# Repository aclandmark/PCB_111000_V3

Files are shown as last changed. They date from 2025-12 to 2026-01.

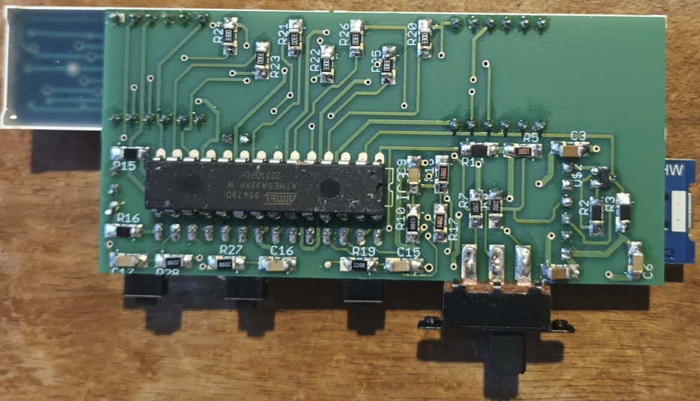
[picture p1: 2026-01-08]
Version 3 design/PCB111000_V3_track side.bmp

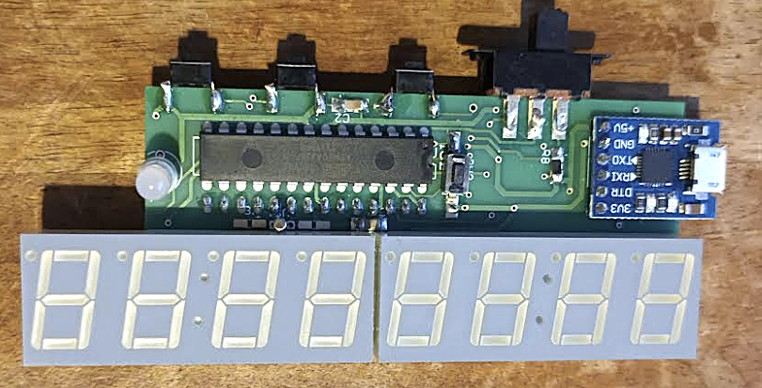
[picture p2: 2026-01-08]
Version 3 design/PCB111000_V3_top side.bmp

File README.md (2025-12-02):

# PCB_111000_V3
This version of PCB_111000 uses a CP2102 USB module
to enable the Atmega devices to communicate with a PC.
This replaces the discreet components used in versions 1 and 2.  
It also makes the PCB cheeper and easier to assemble.

There is one other change: The device that hosts user projects,
an Atmega 168 has been replaced with an Atmega 328.
User projects should not be affected but should be compiled for the
Arduino UNO pcb rather than for the Arduino Nano with an Atmega 168.

Set up procedure for PCB_111000_V3 is the same as that for V2 however
there are slight differences in the programs.
8_UNO_AVR_Programmer_V3 is replaced by UNO_PCB_111000_V3_programmer
5_Project_pcb_168_V2.30_Arduino_V2 is replaced by mini_OS programmer

The original mini-OS generated the user prompt p/r  p/r  p/r.......
An special version was developed that enabled user projects to reset the
mini-OS in the event of a crash.  This version generates the user prompt
p/g  p/g  p/r......... It will ber used in PCB_111000_V3.

No additional changes are expected for the mini-OS, so only the hex files 
are copied into this repository.

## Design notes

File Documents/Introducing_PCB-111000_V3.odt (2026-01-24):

PCB_111000_V3: Getting a new pcb up and running

1. Introduction

PCB_111000_V3 is a development of PCB_111000_V2.

Both pcbs are loaded with two Atmega 328 devices rather than one Atmega328 and one Atmega168.

The first Atmega 328 hosts user projects (The user device).

The second 328 (the mini-OS device) hosts a mini-OS which:

Drives an 8 digit display

Includes an Atmega programmer to programs the user device.

Provides a variety of services for use by user projects

PCB initialisation is carried out using the following Arduino sketches

UNO_PCB_111000_V3_programmer (was 8_UNO_AVR_programmer_V3)

mini_OS programmer (was 5_Project_pcb_168_V2.30_Arduino_V2)

2. Setting up PCB-111000_V2: Basic steps

Step 1 The PCB is loaded with all components except the displays and the Atmega devices

Step 2

Open the sketch “UNO_PCB_111000_V3_programmer”. Under Tools/Board select Arduino UNO. Connect the UNO to the PC check the port number and upload the sketch.

Step 3

Close the sketch assemble the HW (see section 3) and with the aid of the Br@y++ terminal emulator use the UNO to:

Upload “mini_OS programmer” to the user device

Calibrate it’s internal RC oscillator

Allow the user device to run so that it can upload string data to its EEPROM.

Note:

Terminal emulator runs at 38.4KB and uses default settings.

See section 4 for more details.

Step 4 Load the user device onto the PCB111000_V3 and test, then add the mini-OS device.

Step 5

Run “mini_OS programmer” under the control of Br@y++ to setup the mini-OS device (See section 5 for more details) by:

Uploading the mini-OS to its flash

Checking the calibration of its internal RC oscillator.

Uploading the “Hello world” strings to its EEPROM

Step 6 Overwrite “mini_OS programmer” with user projects.

(See sections 6 and 7.)

Step 7 Upgrade the mini_OS if necessary (See section 8).

3. Hardware (HW) details

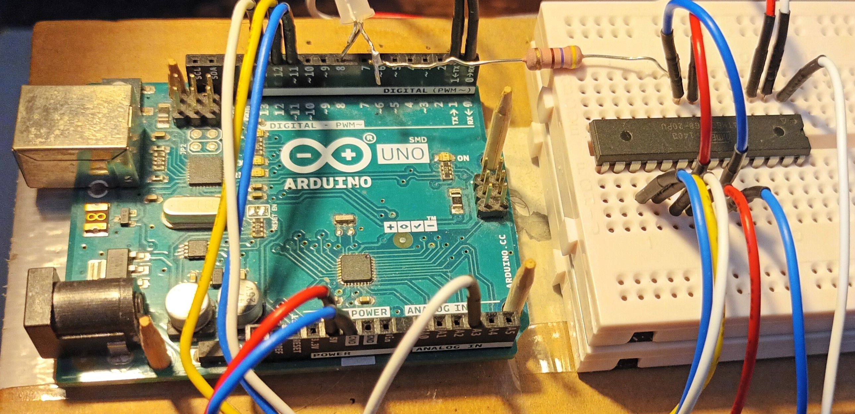
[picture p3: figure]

UNO used to program the user device before it is soldered onto the PCB111000_V3 Note: Atmega328 pin numbers given for a DIP28 device Upload “UNO_PCB_111000_V3_programmer” sketch before placing the user device | UNO | | | Plug-in pcb
| UNO Pin | Atmega 328 | | User device
| | Pin | Function | Pin
| 0 (Rx) | 2 | RXD | 2
| 1 (Tx) | 3 | TXD | 3
| 11 | 17 | MOSI | 17
| 12 | 18 | MISO | 18
| 13 | 19 | SCK | 19
| A3 | 26 | PC3 | 1 (Reset)
| GND | | | 8, 22
| 5V | | | 7,20
| 8 | 14 | PB0 | LED driver

4. Driving “UNO_PCB_111000_V3_programmer”

Having uploaded the sketch to a UNO open Br@y++ and set it up as follows:

8 data bits, 1 stop bit, no parity or handshaking and a baud rate of 38.4KB

Click on “scan” to identify the comm port and then click on connect:

The following user prompt should be generated:

“s/x s/x s/x s/x s/x s/x s/x…………….”

Step 1 Click mouse pointer in the text box (at the bottom of the Br@y++ window) and

press -s- to get

“Atmega 328 detected.

Press -p- to program flash, -r- to run target, -d- to clear the target EEPROM or -x- to escape.”

Step 2 Press -p- and send “mini_OS programmer”

Step 3 Follow instructions to Cal device then get user prompt “P/S P/S P/S………….”

Step 4 Press -s-, change bit rate when asked and send Text_files\on-chip_strings.txt

A bug Sometimes random text following programming. Power cycle and reprogram.

Optional steps

At P/S prompt press -v- to get program name plus version “mini_OS programmer_V1”

Reset UNO and change the BR to 38.4kB to restore user prompt “s s s s s s s…………….”

Press -s- then -d- to clear “on-chip_strings” and cal bytes from the user device EEPROM

Reset UNO to restore user prompt “s s s s s s s…………….”

Press -s- then -t- to recalibrate the Atmega 328 and restore user prompt “P/S P/S…...…”

Reset UNO to restore user prompt “s s s s s s s…………….”

Press -s- then -r- to restore user prompt “P/S P/S P/S………….”

Press -s- and reprogram the on-chip strings

Reset UNO to restore user prompt “s s s s s s s…………….”

Press -s- then -x- to escape

Reprogram the user device and note that it now offers a recalibration

5 Driving “mini_OS programmer”

5.1 Add the user device

Solder the User device to the PCB-111000_V3.

Press the DPDT switch left

Connect the pcb to a PC running Br@y++ running at 57.6KB.

Check the port and the user prompt “P/S P/S P/S…………..” should be generated.

Press -p- and the response TTND (Target not detected) should also be generated.

This confirms that the USB port is working correctly.

5.2 Add the mini-OS device

Solder on the mini-OS device and press -p- again to generate the prompt:

“ATMEGA 328 detected

Press -P- to send a program file -E- to send a text file (or X to escape).

p/e p/e p/e p/e p/e p/e…..”

5.3 Upload the mini-OS hex file

Press -p- and send

PCB_111000_V3\mini-OS_HEX_files\mini_OS_CC_display.hex

When the LED stops flashing send pcb_bootloader_CC.hex

Note: This assumes that Common Cathode displays are to be used. Similar files are present for Common Anode displays.

5.4 Auto cal the mini-OS device

Follow instructions to auto cal the mini-OS device and restore the “P/S……” prompt.

5.5 Upload the “Hello_world” file to the mini-OS device EEPROM

Press -p- then -e- then -w- and send “Text_files\Hello_world.txt several times as requested.

Finally press any key to read back the file from EEPROM.

6. Run two simple User Projects

6A To test programmer

Press the DPDT switch right to get the “p/g p/g p/g …...” (May need to press the pcb reset switch.)

Press -p- and send

PCB_111000_V3\setup_projects\First_test_proj\First_test_proj.ino.standard.hex

At the “p/g p/g p/g …...” prompt press -g- and operate the DPDT switch.

A column of numbers will be printed out.

Press sw1 to repeat.

6B To test the I2C bus

Send PCB_111000_V3\setup_projects\Get_mini_OS_version\Get_mini_OS_version.hex

Press x at the p/g prompt and then 3 to download hello world messages.

If these projects ruin as expected the displays can now safely be added.

7. Load and check the displays

Displays are driven using a multiplexer which can make fault finding difficult.

Repeat as for section 6 but send “PCB_test\PCB_test.ino.standard.hex”. This turns off the multiplexer and illuminates digits one at a time.

Check for dry joints or solder bridges if any segments fail to work.

7A Display brightness

Reload “Get_mini_OS_version.hex” and press -x- at p/g prompt. Then press 4 while holding 2 user switches down.

7B Default user project

Reload “mini_OS_reset.ino.standard. hex”. and press -x- at p/g prompt. This will give the default project.

8. To upgrade the mini_OS

Push the DPDT switch right and press the reset switch.

Press -p- at the “p/g p/g p/g p/g p/g….” user prompt

and send mini_OS programmer

Run the project to get the “P/S P/S P/S………….”

Press S and reload file “on-chip_strings.txt” containing programmer strings

Press P then upload the new mini-OS as described in section 5.3

Note: Remember to delete line :00000001FF from end of new mini-OS file

9. Optional system files

Mini-OS_Resources\Eeprom_subroutines_PRN_alt.c:

In early designs PRN generator write to the EEPROM was too frequent and EEPROM burnout occurred. In this file the PRN uses a different location. It should be used if the

Message from the OS is always the same.

Bootloader_resources\Bootloader_main_with_OS_reset.c

This enables user projects to reset the mini-OS which is necessary if the I2C bus crashes. It was optional for PCB_111000_V2 but is standard for PCB_111000_V3.

See section 14 for more details.

10 SW downloads

There are two essential software applications that must be downloaded onto this PC. They are:

The Arduino development environment. Go to https://www.arduino.cc/en/software and download it from the Microsoft store.

Bray++ version 20130820 which can be downloaded from https://www.sites.google.com/site/terminalbpp/

Almost as important are

The portable version of Programmers notepad which can be downloaded from

http://www.pnotepad.org/download/.

An excellent text written by Joe Pardue that can be downloaded from

https://epdf.pub/c-programming-for-microcontrollers.html

The Atmega data sheet that can be downloaded from

https://www.docdroid.net/Q6jfzd3/atmega48a-pa-88a-pa-168a-pa-328-p-ds-ds40002061a-pdf

11 Getting the PCB manufacturing files

Open the board in Eagle fusion.

Click on the manufacturing tab.

Click on the Export Gerber NC drill……. manufacturing icon then OK

Save as a CamOutputs.zip file when requested

Can now extract files to a CamOutputs directory and remove the “assembly folder” leaving

“DrillFiles” and “GerberFiles” before recompressing the directory.

Send this to a pcb manufacturer.

12. PCB assembly

Fusion/Eagle circuit design and layout drawings can be found under

PCB-111000_V3\Version 3 design together with a parts list.

The Eagle pcb design software is required to view these

Photographs of the pcb are shown below.

Note the locations of the following components

The user switches sw1, sw2 and sw3

The double pole double throw switch (DPDT)

The reset switch

The user device which is in the top side of the pcb (note also the location of pin 1)

The Mini-OS device which is in the under side of the pcb (note also the location of pin 1)

Because of the way the two Atmega devices are assembled the pins of one of them must be soldered from the device side of the board.

Note also the orientation of the two display modules.


| Photo of PCB-111000V3 track side. Solder the mini-OS device to this side Note its placement with pin 1 (towards the middle of the pcb).

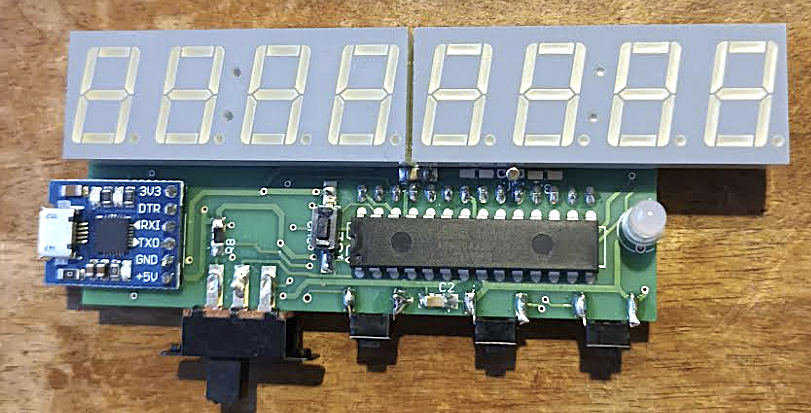
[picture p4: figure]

| Photo of PCB-111000V3 component side. Solder the user device to this side Note its placement with pin 1 (towards the middle of the pcb). User switches left to right are sw1, 2 &3 Note also the orientation of the display modules
Other switches are the DPDT and the reset switch

13 System Block diagram

User device hosts user programs.

Mini-OS device hosts programmer and I2C/display……..application

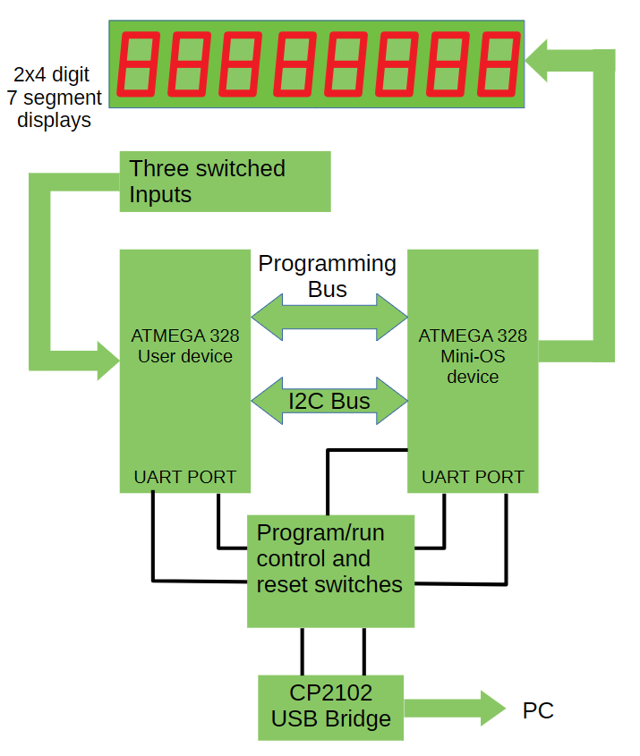
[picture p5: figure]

14 Reset functions

There are three applications that may need to be reset:

The user project.

The programmer

The I2C/display driver

The reset switch

Resets the user project

Passes control in the mini-OS device to the programmer (i.e. a jump to the boot section).

Occasionally it is necessary to

Reset the user project

Pass control in the mini-OS device to the I2C/display code, (a jump to the application section).

This is referred to as a full reset and can be used when a project crashes and the reset switch fails to restart things as required.

To implement a full reset:

User code includes a watch dog time out with ISR.

Control jumps to the ISR when the I2C bus crashes.

This uses a programming wire to signal the mini-OS device and then

applies pulse to its reset pin.

Finally the ISR times out and the user device resets.

Note:

The ISR can also save the variables needed to ensure that the project resumes as required.

Full reset will only be applied to user projects when needed. As an example it has been implemented in

setup_projects\mini_OS_reset\mini_OS_reset.ino.

To indicate that the mini-OS has been implemented to accept full reset the user prompt is changed from

p/r p/r p/r……… to p/g p/g p/g……..

15 Issues

If -p- is pressed at the p/g prompt the first task of the programmer is to switch the target device into programming mode after which its programming memory is reset and the user is requested to send the code. Occasionally the device fails to enter programming mode. It is believed that this unpredictable response may be due to a dry joint in the reset circuitry.

Having pressed -p- at the p/g prompt the user device program space is cleared, in other words the original program can no longer function. In some versions of PCB 111000 this process was delayed until the first character of the new code had been received so that users could safely change their minds after pressing p. This has not been implemented here however as it was not found to be adequately reliable.

The original mini-OS was developed using winAVR will full optimisation, in other words to make the executable file as small as possible. winAVR has been replaced by Studio 7 which generates even smaller code. Optimisation has had to be turned off. The reasons for this have not been investigated but may be due to timing issues.

EEPROM address changes V2 top V3

Cal factors

0x1FF becomes 0x3FF User OSC CAL

0x1FE 0x3FE User OSC CAL

0x1FD 0x3FD Default OSC CAL

0x1FC 0x3FC PRN location

0x1FB 0x3FB PRN location

0x1FA 0x3FA Reset source

0x3F9 Used by mini-OS programmer

All projects: Recompile with new EEPROM locations

Setup projects: All tested

Glitch in reading hello world file:

Text “Do it your own way! Let the others only think they know best”

reads as “Do it your own way! Let the othothers only think they know best”

When downloading and printing files a Tx delay may need setting up in Bray++

All projects recompiled and tested OK

Check text at head of Arduino projects All done

For all projects including Proj_0 use pcb_111000_projects C files

A V3 pcbs loaded and checked except for Displays

Check for !UC !UC !UC response on V1

All OK bar one which was cured by pressing on plug in user device

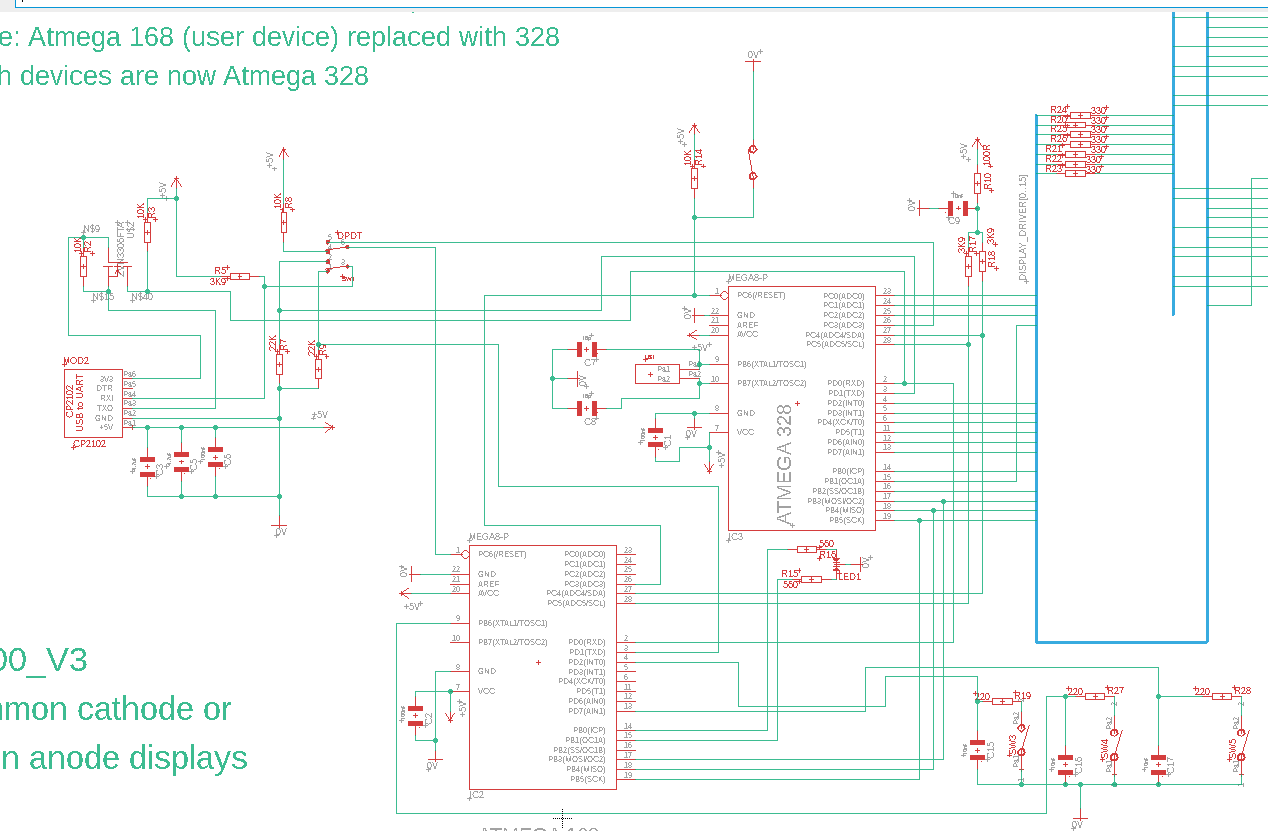
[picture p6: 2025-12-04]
Version 3 design/Schematic.bmp

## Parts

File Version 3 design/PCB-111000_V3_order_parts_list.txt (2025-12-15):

Partslist

Capacitors

18pF (C7, C8)				2 OFF			RS 648-0935		OK	Ordered			RECEIVED
10nF (C9, C15, C16, C17)  		4 OFF			RS 199-2068		OK	Ordered			RECEIVED
100nF (C1, C2, C6) 			3 OFF			RS 669-8417		OK	Ordered			RECEIVED
4.7uF (C3, C5)				2 OFF			RS 723-5076		OK	Ordered			RECEIVED

C4, C10 to 14 missing

Resistors

220R (R27, R28)				2 OFF			RS 812-1849		OK	Ordered			RECEDIVED
330R (R20 to 26)			7 OFF			RS 197-8302		OK	Ordered			RECEIVED
560R (R15, R16)				2 OFF			RS 679-2225		OK	Ordered			RECEIVED
3K9	(R5, R17, R18)			3 OFF			RS 242-6578		OK	Ordered			RECEIVED
10K	 (R2, R3, R8, R14)		4 OFF			RS 679-1765		OK	Ordered			AWAITING
22K	(R7, R9)			2 OFF			RS 223-2439		OK	Ordered			RECEIVED

R1, R4, R6, R11, R12, R13 missing

R10 100R not ordered	Used 220R instead

CC_DUAL_LED			1 OFF		RS 171-2136	OK	Ordered			RECEIVED
Watch Crystal 			1 OFF		RS 171-0553	OK	Ordered			RECEIVED
MOSFET ZVN3306FTA		1 OFF		RS 275-945	OK	Ordered			RECEIVED

Extras
6 way header x 3 Radio Spares 				681-2994				RECEIVED 
Bread board jumper wires		RS Stock No.:	505-3374	505-3403 		RECEIVED
2 Watt wired resistor 					707-8849				RECEIVED 				

Others
4_DIGIT_7SEGMENT_DISPLAY		CA56-12SYKWA	2 OFF	872-1954	Ordered		RECEIVED

4_DIGIT_7SEGMENT_DISPLAY	CC56-21SURKWA	RS 165-4368  Pack of ten NOT AVAZILABLE

Atmega 328	ATMEGA328-PU	RS 131-0277			OK	
Atmega 168	ATMEGA168PA-PU	RS 127-8268			OUT OF STOCK	

For parcell tracking
Sold to				12277347
Order ref number	3015071146

CP2102 					1 OFF
DPDT switch				1 OFF		RE  78-0560	OK
SM NO push button 		1 OFF		RE 51-0709 	OK
Push button switch		3 OFF		RE 51-0711	OK
Solder wick							Ordered from RE

      DHL eCommerce UK Swindon
      Unit 1 Ignition Park
      Dorcan
      Swindon
      SN3 5HS
Sender s reference: 1259602840 

Your shipment 31542913837470 (1 parcel expected) is delivered
Sender s reference: 1259602840

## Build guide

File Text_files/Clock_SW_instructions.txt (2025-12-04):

"Having entered the time it is also possible to reconnct the pcb to a 5V supply.Then press sw3/sw1 to start the clock. 
Toggle sw1 to switch between the clock and a new SW or press sw2 to select old SW.
Press sw3 to pause, blank or resume the display.
To adjust the time: Press sw1 to restore clock time then immediately press sw3.
Release sw3 to increment time or sw1 to decrement it then both switches to restore normal operation.
Press sw3 or 2 then sw1 to continue."

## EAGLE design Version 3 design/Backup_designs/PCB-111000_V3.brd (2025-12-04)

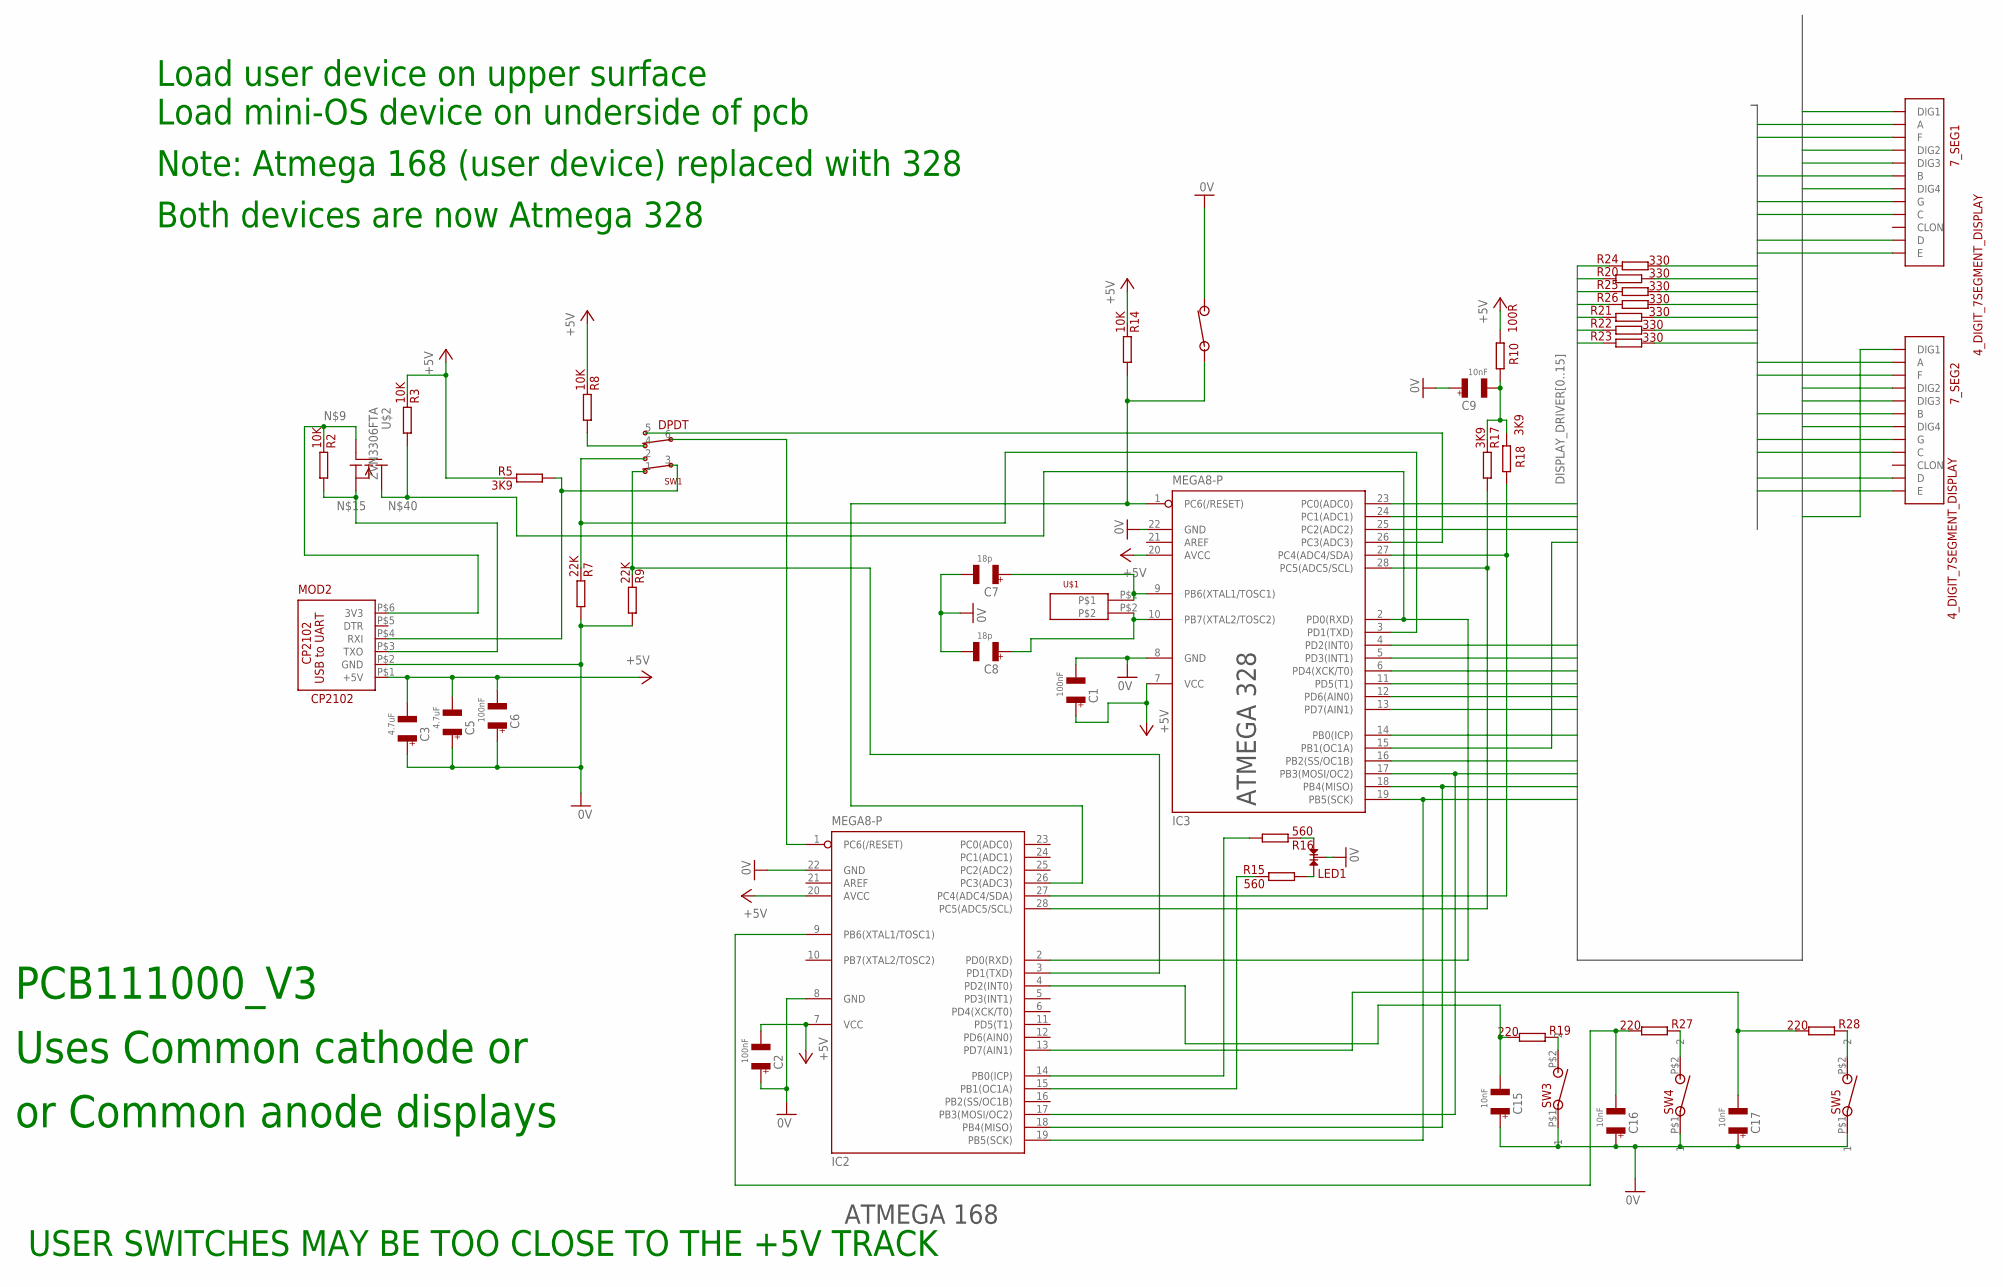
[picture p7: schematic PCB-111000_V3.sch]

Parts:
7_SEG1, 7_SEG2: 4_DIGIT_7SEGMENT_DISPLAY
C1, C2, C6: 100nF; 1206@1
C3, C5: 4.7uF; 1206@1
C7, C8: 18p; 0805
C9, C15, C16, C17: 10nF; 1206@1
IC2, IC3: MEGA8-P; DIL28-3
LED1: LED; CA_DUAL_LED
MOD2: CP2102
R2, R3, R8, R14: 10K; 1206
R5, R17, R18: 3K9; 1206
R7, R9: 22K; 1206
R10: 100R; 1206
R15, R16: 560; 1206
R19, R27, R28: 220; 1206
R20, R21, R22, R23, R24, R25, R26: 330; 1206
SW1: DPDT; DPDT_SWITCH
SW2: NO_SW; SM_NO_PUSH_BUTTON
SW3, SW4, SW5: NO_PB_1; RE51-0711
U$1: XTAL; XTAL_VIAS
U$2: ZVN3306FTA; SOT-23

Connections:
0V: C1.P$2 (2), C2.P$1 (1), C3.P$1 (1), C5.P$1 (1), C6.P$1 (1), C7.2, C8.2, C9.P$1 (1), C15.P$1 (1), C16.P$1 (1), C17.P$1 (1), IC2.8 (GND), IC2.22 (GND), IC3.8 (GND), IC3.22 (GND), LED1.2, MOD2.P$2 (GND), R7.P$1, R9.P$1, SW2.P$2 (2), SW3.P$1 (1), SW4.P$1 (1), SW5.P$1 (1)
+5V: C1.P$1 (1), C2.P$2 (2), C3.P$2 (2), C5.P$2 (2), C6.P$2 (2), IC2.7 (VCC), IC2.20 (AVCC), IC3.7 (VCC), IC3.20 (AVCC), MOD2.P$1 (+5V), R3.P$2, R5.P$2, R8.P$2, R10.P$2, R14.P$2
DISPLAY_DRIVER0: IC3.15 (PB1(OC1A)), R24.P$2
DISPLAY_DRIVER1: IC3.4 (PD2(INT0)), R20.P$2
DISPLAY_DRIVER2: IC3.5 (PD3(INT1)), R25.P$2
DISPLAY_DRIVER3: IC3.6 (PD4(XCK/T0)), R26.P$2
DISPLAY_DRIVER4: IC3.11 (PD5(T1)), R21.P$2
DISPLAY_DRIVER5: IC3.12 (PD6(AIN0)), R22.P$2
DISPLAY_DRIVER6: IC3.13 (PD7(AIN1)), R23.P$2
DISPLAY_DRIVER8: 7_SEG2.P$12 (DIG1), IC3.14 (PB0(ICP))
DISPLAY_DRIVER9: 7_SEG2.P$9 (DIG2), IC3.16 (PB2(SS/OC1B))
DISPLAY_DRIVER10: 7_SEG2.P$8 (DIG3), IC2.17 (PB3(MOSI/OC2)), IC3.17 (PB3(MOSI/OC2))
DISPLAY_DRIVER11: 7_SEG2.P$6 (DIG4), IC2.18 (PB4(MISO)), IC3.18 (PB4(MISO))
DISPLAY_DRIVER12: 7_SEG1.P$12 (DIG1), IC2.19 (PB5(SCK)), IC3.19 (PB5(SCK))
DISPLAY_DRIVER13: 7_SEG1.P$9 (DIG2), IC3.23 (PC0(ADC0))
DISPLAY_DRIVER14: 7_SEG1.P$8 (DIG3), IC3.24 (PC1(ADC1))
DISPLAY_DRIVER15: 7_SEG1.P$6 (DIG4), IC3.25 (PC2(ADC2))
unnamed: IC2.14 (PB0(ICP)), R16.P$1
unnamed: IC2.15 (PB1(OC1A)), R15.P$2
unnamed: LED1.1, R15.P$1
unnamed: LED1.3, R16.P$2
unnamed: IC3.26 (PC3(ADC3)), SW1.5
unnamed: IC3.3 (PD1(TXD)), R7.P$2, SW1.2
unnamed: R27.P$2, SW4.P$2 (2)
unnamed: R19.P$2, SW3.P$2 (2)
unnamed: MOD2.P$6 (3V3), R2.P$2, U$2.3 (G)
unnamed: C7.1, IC3.9 (PB6(XTAL1/TOSC1)), U$1.P$1
unnamed: C17.P$2 (2), IC2.13 (PD7(AIN1)), R28.P$1
unnamed: C8.1, IC3.10 (PB7(XTAL2/TOSC2)), U$1.P$2
unnamed: R8.P$1, SW1.4
unnamed: IC2.3 (PD1(TXD)), R9.P$2, SW1.1
unnamed: MOD2.P$3 (TXO), R2.P$1, U$2.2 (S)
unnamed: R28.P$2, SW5.P$2 (2)
unnamed: C15.P$2 (2), IC2.4 (PD2(INT0)), R19.P$1
unnamed: C16.P$2 (2), IC2.9 (PB6(XTAL1/TOSC1)), R27.P$1
unnamed: C9.P$2 (2), R10.P$1, R17.P$2, R18.P$2
unnamed: IC2.1 (PC6(/RESET)), SW1.6
unnamed: IC2.26 (PC3(ADC3)), IC3.1 (PC6(/RESET)), R14.P$1, SW2.P$1 (1)
unnamed: MOD2.P$4 (RXI), R5.P$1, SW1.3
unnamed: IC2.28 (PC5(ADC5/SCL)), IC3.28 (PC5(ADC5/SCL)), R17.P$1
unnamed: IC2.27 (PC4(ADC4/SDA)), IC3.27 (PC4(ADC4/SDA)), R18.P$1
unnamed: IC2.2 (PD0(RXD)), IC3.2 (PD0(RXD)), R3.P$1, U$2.1 (D)
SEVEN_SEG0: 7_SEG1.P$11 (A), 7_SEG2.P$11 (A), R24.P$1
SEVEN_SEG1: 7_SEG1.P$7 (B), 7_SEG2.P$7 (B), R20.P$1
SEVEN_SEG2: 7_SEG1.P$4 (C), 7_SEG2.P$4 (C), R25.P$1
SEVEN_SEG3: 7_SEG1.P$2 (D), 7_SEG2.P$2 (D), R26.P$1
SEVEN_SEG4: 7_SEG1.P$1 (E), 7_SEG2.P$1 (E), R21.P$1
SEVEN_SEG5: 7_SEG1.P$10 (F), 7_SEG2.P$10 (F), R22.P$1
SEVEN_SEG6: 7_SEG1.P$5 (G), 7_SEG2.P$5 (G), R23.P$1

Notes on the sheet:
ATMEGA 168
ATMEGA 328
or Common anode displays
PCB111000_V3
Uses Common cathode or
USER SWITCHES MAY BE TOO CLOSE TO THE +5V TRACK
Load mini-OS device on underside of pcb
Load user device on upper surface
Note: Atmega 168 (user device) replaced with 328
Both devices are now Atmega 328

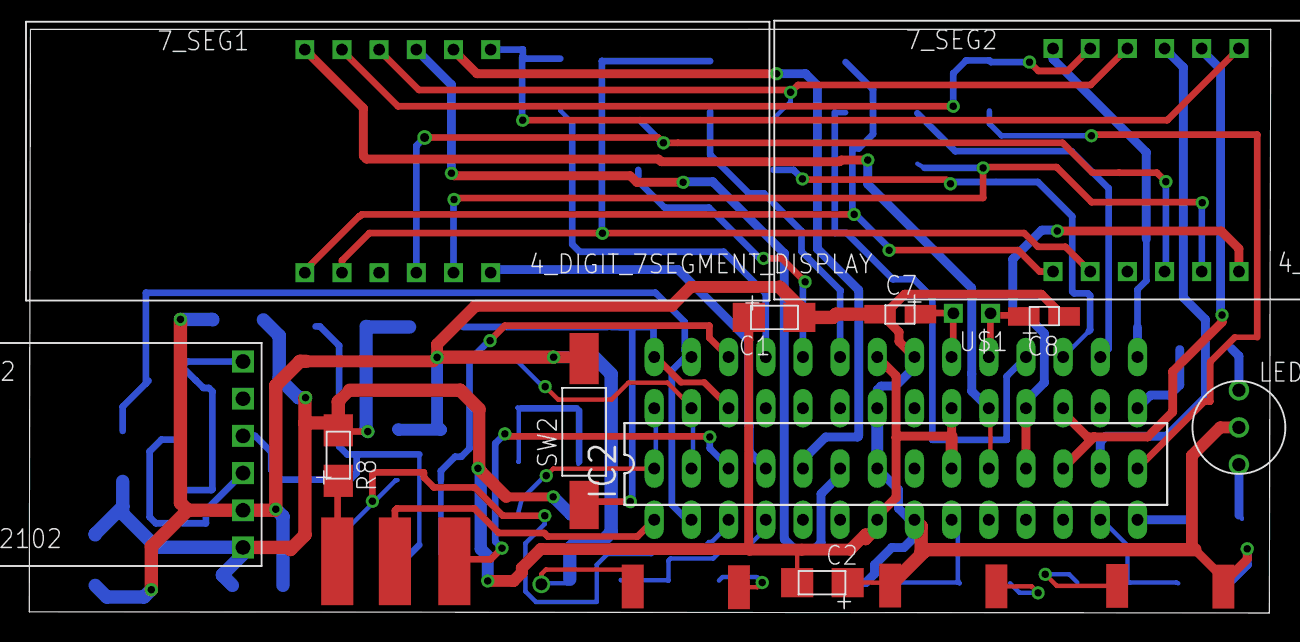
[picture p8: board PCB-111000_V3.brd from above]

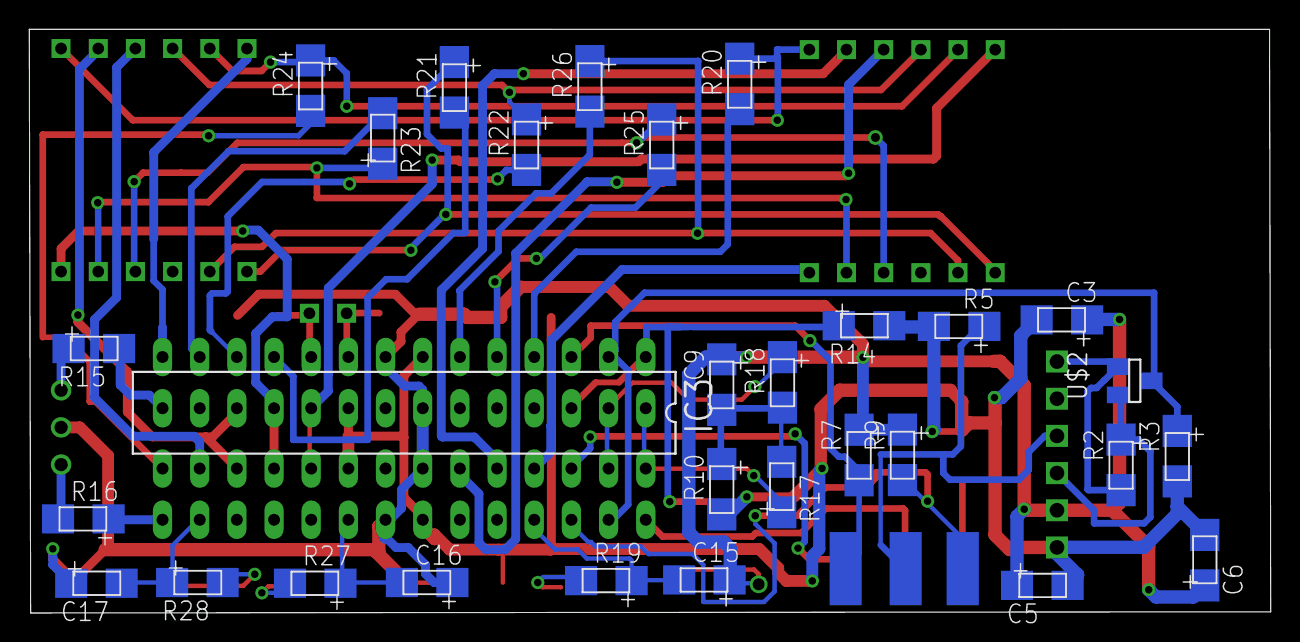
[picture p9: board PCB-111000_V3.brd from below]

Board: 2 copper layers, 84.8 x 39.9 mm, 46 parts (31 on the bottom side), 49 nets.

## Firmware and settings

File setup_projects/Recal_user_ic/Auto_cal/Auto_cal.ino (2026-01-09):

/*Proj_9B_168_auto_cal
************************************************************************/


/*IT INTRODUCES

1.  Project subroutine "emergency_cal()". 
  This is like subroutine "compute_error()" but quicker and less accurate.

2.  Project subroutine "Calibration_tuning()".
  This automatically attempts to find the best value for OSCCAL.

Note: Proj_9B can be used if the default value of OSCCAL is not good enough for PC comms. */


#include "Proj_9B_header_file.h"


volatile char T1_OVF;
volatile long error_SUM;
unsigned char OSCCAL_WV, OSCCAL_DV, New_UC_value;
volatile int EA_counter, EA_buff_ptr;
char cal_mode;
char Num_string[12];


int main (void){
long error;

setup_HW_Arduino_IO;                                                  //"setup_HW" initially saves default OSCCAL in 0x3FD and

TIMSK1 |= (1 << TOIE1);                                               //Enable T1 interrupt
I2C_initiate_7_8125mS_ref();                                           //Request Mode P: 7.8125mS ref signal from master


/*****Waiting for first I2C tick***********/
waiting_for_I2C_master;                                                //Energise slave I2C and wait for master
send_byte_with_Nack(1);                                               //Master will respond by staying in mode P
clear_I2C_interrupt;                                                  //House keeping
TCNT1=0;TCCR1B = 1;                                                   //Start T1 with no pre-scaling (at 8MHz)
sei();  


cal_mode = 1;   
for(int m = 0; m < 15; m++)error = emergency_cal();                   //warm-up time

for(int m = 0x10; m <= 0xF0; m++){                                    //results are stored in array "buffer"
OSCCAL = m; if (!(m%5))Serial.write('.');
if ((error = emergency_cal()) < 1000)break;}
waiting_for_I2C_master;
send_byte_with_Nack(0);                                             //Master responds by exiting mode P
clear_I2C_interrupt;
TIMSK1 &= (~(1 << TOIE1));                                          //Disable T1 interrupt
newline_A(); 
Serial.write("Approx. cal factor ");Hex_to_PC_A(OSCCAL, Num_string, ' ');  
Serial.write("   Error "); Int_Num_to_PC_A(error, Num_string, '\r');

cal_mode = 5;
TIMSK1 |= (1 << TOIE1);                                               //Enable T1 interrupt
I2C_initiate_7_8125mS_ref();    
waiting_for_I2C_master;
send_byte_with_Nack(1);                                               //Master responds by staying in mode P
clear_I2C_interrupt;
TCNT1=0;TCCR1B = 1;                                                   //Start T1
sei();                                                                //Global interrupt enable
OSCCAL_WV = OSCCAL;
error =  Calibration_tuning(OSCCAL_WV);                               //Fine tuning: First step may terminate in a subsidiary dip 
if (error > 500) error =  Calibration_tuning(OSCCAL + 4);             //Fine tuning: Second step to locate main dip 
if (error > 500) error =  Calibration_tuning(OSCCAL - 2);
if (error > 500) OSCCAL_WV = OSCCAL;

waiting_for_I2C_master;
send_byte_with_Nack(0);                                               //Master responds by exiting mode P
clear_I2C_interrupt;
Serial.write("Cal factor ");
Hex_to_PC_A(OSCCAL, Num_string, ' ');
Serial.write("   Error ");
Int_Num_to_PC_A(error, Num_string, ' ');


Serial.write("\r\nSave? y or AOK\r\n");
if(waitforkeypress_A() == 'y'){
New_UC_value = OSCCAL;


eeprom_write_byte((uint8_t*)0x3FE, New_UC_value);                     //Save new user cal value to EEPROM addresses 0x1F7 and 8
Timer_T0_sub(T0_delay_10ms);
eeprom_write_byte((uint8_t*)0x3FF, New_UC_value);
Timer_T0_sub(T0_delay_10ms);

    
Serial.write("Values saved to EEPROM   ");                              //Echo values back from the EEPROM
Hex_to_PC_A(eeprom_read_byte((uint8_t*)0x3FE), Num_string, ' ');
Serial.write ("    ");
Hex_to_PC_A(eeprom_read_byte((uint8_t*)0x3FF), Num_string, ' ');
newline_A();}
else Serial.write("Not saved\r\n");

Serial.write("\r\nAK to repeat\r\n");
  waitforkeypress_A();SW_reset;}




/**********************************************************************************************/
long emergency_cal(void)  
    {long error;
    waiting_for_I2C_master_with_ISR;                                //TWI generates interrupt every 7.8125mS 
    EA_counter = 0;                                                 //Compute error for each value of OSCCAL 10 times
    error_SUM = 0;
    while(EA_counter < 2);EA_counter = 0;TWCR = 0;                  //wait here for 2 TWI interrupts
    error = error_SUM;
    if (error < 0) error *= (-1);                                   //Only interested in the magnitude of the error
    return error;}                                                  //return average error values
  


/**********************************************************************************************/
long compute_error(void)  
    {long error;
    waiting_for_I2C_master_with_ISR;
    EA_counter = 0;                                                   //Compute error for each value of OSCCAL 10 times
    error_SUM = 0;
    while(EA_counter < 15);EA_counter = 0;TWCR = 0;                    //wait here for 15 TWI interrupts
    error = error_SUM;
    if (error < 0) error *= (-1);                                     //Only interested in the magnitude of the error
    return error/10;}                                                 //return average error values



/**********************************************************************************************/
ISR(TIMER1_OVF_vect){T1_OVF++; }                                        //T1 should count to 62500 in 7.8125ms.



/************************************************************************************************/
ISR(TWI_vect){                                                          //T2 (mini_OS) overflows: giving a calibrated tick rate
long TCNT1_BKP;
TWDR;                                                                   //Read TWDR the data register
send_byte_with_Nack(1);                                                 //Master responds by remaining in mode P
clear_I2C_interrupt;

TCCR1B = 0;                                                             //Halt T1
TCNT1_BKP = TCNT1;                                                      //Copy the value of TCNT1
TCNT1 = 0;                                                              //Clear TCNT1
TCCR1B = 1;                                                             //Get T1 running again ASAP (Note T2 (mini_OS) has not stopped running)
if(EA_counter < cal_mode)T1_OVF = 0;                                    //Ignore first result for "emergency_cal()" or first 5 for "compute_error"
else
{switch(T1_OVF){
case 0: error_SUM = error_SUM + (TCNT1_BKP - 62500); break;
case 1: error_SUM = error_SUM + (TCNT1_BKP - 62500 + 65536); break;
case 2: error_SUM = error_SUM + (TCNT1_BKP - 62500 + 131072); break;}
T1_OVF = 0;}                                                             //Sum error results fo the next 20 TWI interrupts
EA_counter++;                                                            //counter increments up to 25.
waiting_for_I2C_master_with_ISR;}                                       //Be ready for next TWI interrupt 



/**********************************************************************************************/
/*void I2C_initiate_7_8125mS_ref(void){
char num_bytes=0;
char mode = 'U';
waiting_for_I2C_master;
send_byte_with_Ack(num_bytes);
send_byte_with_Nack(mode);
clear_I2C_interrupt;} */


/**********************************************************************************************/  
long Calibration_tuning(char OSCCAL_test)
    {long cal_error, error_mem; 
    OSCCAL = OSCCAL_test;   
    cal_error = compute_error();                                      //compute error for OSCCAL_test
    error_mem = cal_error;
    OSCCAL++;                                                        //increment OSCALL
    while(1){
    cal_error = compute_error();                                      //Calculate new error
    if (cal_error > error_mem) {                                      //If it gets worse
    OSCCAL--; break;}                                                 //decrement OSCCAL and exit             
    error_mem = cal_error;              
    OSCCAL++;}
    if (OSCCAL != OSCCAL_test)  return error_mem;                     //REPLACE with OSCCAL_DV when OSCCAL_test is discarded
    else{                                                             //OSCCAL is still the default value
    OSCCAL--;
    while(1){
    cal_error = compute_error();
    if (cal_error > error_mem){                                       //If it gets worse
    OSCCAL++;
    break;}                                                           //increment OSCCAL and exit
    error_mem = cal_error;              
    OSCCAL--;}}
    return error_mem;}



    /*************************************************************************************************************************************/

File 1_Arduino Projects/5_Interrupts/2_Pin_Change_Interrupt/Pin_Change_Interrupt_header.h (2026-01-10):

#include <avr/wdt.h>

char watch_dog_reset = 0;

#define T0_delay_10ms 5,178
#define T1_delay_100ms 3, 0x9E62
#define T2_delay_10ms 7,178


#define set_up_PCI_on_sw2           PCICR |= (1 << PCIE0);
#define enable_pci_on_sw2           PCMSK0 |= (1 << PCINT6);


#define switch_3_down  ((PIND & 0x80)^0x80)
#define switch_3_up   (PIND & 0x80)
#define switch_1_down ((PIND & 0x04)^0x04)
#define switch_1_up   (PIND & 0x04)
#define switch_2_down ((PINB & 0x40)^0x40)
#define switch_2_up   (PINB & 0x40)

/*****************************************************************************/
#define setup_HW \
setup_watchdog;\
set_up_I2C;\
ADMUX |= (1 << REFS0);\
set_up_switched_inputs;\
Set_LED_ports;\
Unused_I_O;\
eeprom_write_byte((uint8_t*)(0x3FD),OSCCAL);\
while (!(PIND & (1 << PD1)));\
Timer_T0_10mS_delay_x_m(5);\
OSC_CAL;\
setup_PC_comms_Basic(0,16);\
I2C_Tx_LED_dimmer();\
\
\
/*OPTIONAL Setup_HW code gives default ap*/\
Timer_T0_10mS_delay_x_m(1);\
I2C_TX_328_check();\
waiting_for_I2C_master;\
if (receive_byte_with_Nack()==1)\
{TWCR = (1 << TWINT);\
wdt_enable(WDTO_30MS);\
I2C_Tx_display();}\
else TWCR = (1 << TWINT);



/*****************************************************************************/
#define setup_watchdog \
if (MCUSR & (1 << WDRF))watch_dog_reset = 1;\
wdr();\
MCUSR &= ~(1<<WDRF);\
WDTCSR |= (1 <<WDCE) | (1<< WDE);\
WDTCSR = 0;

#define wdr()  __asm__ __volatile__("wdr")

#define SW_reset {wdt_enable(WDTO_30MS);while(1);}



/*****************************************************************************/
#define set_up_I2C \
TWAR = 0x02;



/*****************************************************************************/
#define set_up_switched_inputs \
MCUCR &= (~(1 << PUD));\
DDRD &= (~((1 << PD2)|(1 << PD7)));\
PORTD |= ((1 << PD2) | (1 << PD7));\
DDRB &= (~(1 << PB6));\
PORTB |= (1 << PB6);



/*****************************************************************************/
#define Unused_I_O \
MCUCR &= (~(1 << PUD));\
DDRB &= (~((1 << PB2)|(1 << PB7)));\
DDRC &= (~((1 << PC0)|(1 << PC1)|(1 << PC2)));\
DDRD &= (~((1 << PD3)|(1 << PD4)|(1 << PD5)|(1 << PD6)));\
PORTB |= ((1 << PB2)|(1 << PB7));\
PORTC |= ((1 << PC0)|(1 << PC1)|(1 << PC2));\
PORTD |= ((1 << PD3)|(1 << PD4)|(1 << PD5)|(1 << PD6));



/*****************************************************************************/
#define Set_LED_ports   DDRB = (1 << DDB0) | (1 << DDB1);
#define LEDs_on       PORTB |= (1 << PB0)|(1 << PB1);
#define LEDs_off      PORTB &= (~((1 << PB0)|(1 << PB1)));
#define LED_1_on      PORTB |= (1 << PB1);
#define LED_1_off     PORTB &= (~( 1<< PB1)); 
#define LED_2_off     PORTB &= (~(1 << PB0));
#define LED_2_on      PORTB |= (1 << PB0);

#define Toggle_LED_1 \
if (PORTB & (1 << PB1)){LED_1_off;}\
else {PORTB |= (1 << PB1);}



/*****************************************************************************/
#define OSC_CAL \
if ((eeprom_read_byte((uint8_t*)0x3FE) > 0x0F)\
&&  (eeprom_read_byte((uint8_t*)0x3FE) < 0xF0) && (eeprom_read_byte((uint8_t*)0x3FE)\
== eeprom_read_byte((uint8_t*)0x3FF))) {OSCCAL = eeprom_read_byte((uint8_t*)0x3FE);}




/*****************************************************************************/
#define diagnostic_mode \




/*****************************************************************************/
#define waiting_for_I2C_master \
TWCR = (1 << TWEA) | (1 << TWEN);\
while (!(TWCR & (1 << TWINT)));\
TWDR;

#define clear_I2C_interrupt \
TWCR = (1 << TWINT);



/*****************************************************************************/
#include "Resources_nano_projects/Subroutines/HW_timers.c"
#include "Resources_nano_projects/PC_comms/Basic_Rx_Tx_Basic.c"
#include "Resources_nano_projects/Chip2chip_comms/I2C_subroutines_1.c"
//#include "Resources_nano_projects/I2C_Subroutines/I2C_subroutines_2.c"
#include "Resources_nano_projects/Chip2chip_comms/I2C_slave_Rx_Tx.c"
//#include "Resources_nano_projects/I2C_Subroutines/I2C_diagnostic.c"
#include "Resources_nano_projects/Subroutines/Random_and_prime_nos.c"




/******************************************************************************/

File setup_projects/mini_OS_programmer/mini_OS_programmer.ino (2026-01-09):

/*****ATMEGA programmer "5_Project_pcb_168_V2.30_Arduino_V2" developed specially for the "Github_PCB-111000_V2" Project 


*******Runs on the Atmega 168
*******See also "8_UNO_AVR_Programmer_V3" which programs the Atmega 168 


********The Atmega 168 is the used to 
********program the ATMEGA 328 EEPROM with the "Hello World" text file and 
********flash with the mini-Os plus pcb-bootloader**********

Push the DPDT switch left and get the "P/S   P/S   P/S........" user prompt on the Br@y++ terminal program set to 57600Baud

  Press "V" to retrieve version details
  Press P to program the mini-OS+pcb-bootloader or EEEPROM

  Press -p- again and send the mini-OS parts 1 and 2 followed by the bootloader
  Follow instruction to calibrate the Atmega 328

  When the "P/S   P/S   P/S........" user prompt is restoted press -p- then -e-
  and send the "Hello World" text file.

  To run bootloader acquire the standard user prompt "P/S   P/S   P/S........" 
switch the DPDT to the right and press the reset switch.

The user prompt changes to "p/r   p/r   p/r   p/r........"

Press -p- and send a user project file
Press -x- to run the file and operate the DPDT switch
Press-3- to read the "Hello world" strings
Press -x- to run the project

To update the mini-OS

At the "p/r   p/r   p/r   p/r........" prompt press -p- and send "5_Project_pcb_168_V2.30_Arduino_V2"
Press -r- and operate the DPDT to get the "P/S   P/S   P/S......" prompt
Press -s- to restore the on-chip strings
Press -p- twice to update the mini-OS
Press -p- then -e- then -r- to check the EEPROM

Operate the DPDT and prress the reset switch to restore the "p/r   p/r   p/r   p/r........" prompt
*/




#include "mini_OS_programmer_header.h"

#define Version "\r\nmini_OS programmer_V1"




int main (void){ 
unsigned int target_type = 0, target_type_M;  
char keypress, sign;
char op_code = 0;
unsigned char fuse_H = 0;
int long cal_error;
long error_up, error_down, error_percent;

cal_factor= 0;                                                  //Set to 1 by OSC_CAL if user cal is available
setup_HW;



/*************************************UNO calibrates Atmega168 if necessary*******************************************/

if(!(eeprom_read_byte((uint8_t*)(0x3FA))))                      //Cleared by 8_UNO_AVR_Programmer_V3 
{
  sendString("\r\nready to autocal\r\n");
  
  Auto_cal_168(0);                                                 //Search starting from 0xF0
  OSCCAL += 1;                                                  //Check performance for OSCCAL_WV +/- 1
  sei();
  error_up = compute_error_UNO(0,2,0);                          //Check that OSCCAL_WV is not at a
  OSCCAL -=2; error_down = compute_error_UNO(0,2,0);            //discontinuity on the
  
  OSCCAL += 1;                                                  //Restore OSCCAL to OSCCAL_WV
  if ((error_up > 500) || (error_down > 500))                     //500
  {sendString
  ("\r\nPoor result: Searching for alternative value\r\n");
  Auto_cal_168(1);} 
save_cal_values(OSCCAL_WV); 

sendString("\r\nDefault OSCCAL value ");
Num_to_PC(10,OSCCAL_DV);
sendString("\r\nNew OSCCAL value ");
Num_to_PC(10,OSCCAL_WV);

newline();
sei();
error_percent = compute_error_UNO(0,2,1)*100/32768;
if(!(error_percent)){sendString("\r\nError less than 1%\r\n");}
 else 
 { sendString("\r\nError = "); Num_to_PC(10,error_percent);
  sendString("%\r\n");}

sendString("-x- to check cal (15 Sec pause) or AOK to escape\r\n\r\n");
if (waitforkeypress() == 'x')

{Timer_T0_sub(T0_delay_20ms);
OSCCAL -= 20;
osccal_MIN = OSCCAL;                                          //Compute cal error for 41 values of OSCCAL
  for(int m = 0; m <= 40; m++)
  {cal_error = compute_error_UNO(1,2,1);OSCCAL++;}
  OSCCAL = OSCCAL_WV;                                           //Restore working value of OSCCAL
  
 for(int m = 0; m <= 40; m++)                                    //Print table of values
  {Num_to_PC(10,osccal_MIN); osccal_MIN++;
    sendChar('\t');Num_to_PC(10,buffer[m]);
    sendChar('\t');
    percentage_error = buffer[m];
    Num_to_PC(10,percentage_error*100/32768);sendChar('%');
    newline();
    Timer_T0_sub(T0_delay_20ms);
    Timer_T0_sub(T0_delay_20ms);
  Timer_T0_sub(T0_delay_20ms);}}

  
eeprom_write_byte((uint8_t*)(0x3FA),0xFF);}



/*************Program Entry point when Atmega 168 is fitted to PCB111000_V2************************************/

if (watchdog_reset == 1)watchdog_reset = 0;             //Set to 1 after mini-OS device has been calibrated
else



/********************************Read Atmega 328 (mini-OS device) calibration**************************************/

{if ((eeprom_read_byte((uint8_t*)0x3FA) == 1)\
&& (MCUSR & (1 << PORF)));                              //POR after programing target device
else  {wdt_enable(WDTO_60MS); while(1);}

while(1){                                               //User prompt is R
do{sendString("R   ");} 
while((isCharavailable(100) == 0));                     //Keypress R to complete target calibration
if(receiveChar() == 'R')break;}

eeprom_write_byte((uint8_t*)0x3FA, 0xFF);                 //Clear EEPROM location set by programmer
MCUSR &= (~(1 << PORF));

waiting_for_I2C_master;                                   //Receive cal data over I2C bus             
OSCCAL_WV = receive_byte_with_Ack();          
cal_error = receive_byte_with_Ack();          
cal_error = (cal_error << 8) + receive_byte_with_Nack();
clear_I2C_interrupt;

Text_target_cal; sendString("  ");
Num_to_PC(10, OSCCAL_WV);
sendChar('\t');
sendString("error "); 
 
 cal_error = cal_error/625;
 if(!(cal_error))sendString("less than 1%\r\n\r\n");
 else {Num_to_PC(10, cal_error);sendString("%\r\n\r\n");}
 
 
 wdt_enable(WDTO_60MS); while(1);}                        //SW reset and jump straight to user prompt P       



/************************Program entry point to program mini-OS or reinstate Atmega168 eeprom*************/

while(1){
do{sendString("P/S   ");} 
while((isCharavailable(255) == 0));  

switch(receiveChar()){

case 'S': case 's': Prog_on_chip_EEPROM();                  //Program on-chip EEPROM
wdt_enable(WDTO_60MS); while(1);break;

case 'v': case 'V': sendString (Version);
newline(); wdt_enable(WDTO_60MS); while(1);break;

case 'P': case 'p': fuse_H = 0xD0;  op_code =1; break;       //Program reset vector to 0x7000            
case 'X': case 'x': fuse_H = 0xD7; op_code =1; break;        //Program reset vector to zero                        

default:break;}if(op_code)break;}                           //Only exit loop the program target 
    
boot_target;
Atmel_powerup_and_target_detect;        
Text_Atmega;

switch (target){
case 168: sendString ("168: Not supported"); wdt_enable(WDTO_1S); break;  
case 328: sendString ("328"); PageSZ = 0x40; PAmask = 0x3FC0; 
FlashSZ=0x4000;break;      
default: wdt_enable(WDTO_1S); while(1);break;}  

Text_detected;
Text_Press_P_or_E;

while(1){
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

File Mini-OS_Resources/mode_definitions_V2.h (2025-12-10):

/********************************************************************************************/
#define I2C_Tx_2_integers \
for (int m = 0; m < 4; m++){\
	display_buf[m] = I2C_data[m];}\
	for (int m = 4; m < 8; m++)display_buf[m] = 0;
	


/********************************************************************************************/
#define I2C_Tx_any_segment \
letter = I2C_data[0];\
digit_num = I2C_data[1];\
switch (letter){\
case 'A': case 'a': letter = 0; break;\
case 'B': case 'b': letter = 3; break;\
case 'C': case 'c': letter = 4; break;\
case 'D': case 'd': letter = 2; break;\
case 'E': case 'e': letter = 5; break;\
case 'F': case 'f': letter = 6; break;\
case 'G': case 'g': letter = 1; break;\
default: letter = 8; break;	}\
if(letter == 8)break;\
if((digit_num >= 8) || (digit_num < 0))break;\
\
if (mode == 2){clear_digits;clear_display;clear_display_buffer;}\
if (mode == 3){if(display_buf[letter] & (1 << digit_num))display_buf[letter] &= (~(1 << digit_num));\
else display_buf[letter] |= (1 << digit_num);} 



/********************************************************************************************/
# define I2C_Tx_8_byte_array \
for (int m = 0; m < 8; m++){\
display_buf[m] = I2C_data[m];}



/********************************************************************************************/
#define I2C_Tx_display_char \
output_2 =  I2C_data[0];\
sign_bit = I2C_data[1];\
for (int m = 0; m < 8; m++)display_buf[m] = 0;\
if (sign_bit == 's') {Disp_CharS (output_2);}\
if (sign_bit == 'u') {Disp_CharU (output_2);}



/********************************************************************************************/
#define I2C_Tx_long \
L_number = 0;\
for (int m = 0; m < 4; m++){\
L_number += I2C_data[m];\
if(m<3) L_number = L_number << 8;}\
Display_num(L_number);



/********************************************************************************************/
#define I2C_initiate_10mS_ref \
TCCR2B = 2;\
TIMSK2 |= ((1 << OCIE2A) | (1 << TOV2));\
wdt_enable(WDTO_120MS);



/********************************************************************************************/
# define I2C_Tx_BWops \
for (int m = 0; m < 8; m++){\
display_buf[m] = I2C_data[m];}



/********************************************************************************************/
#define I2C_displayToLong \
L_number=0;\
sign = '+';\
{int m = 7; while (!(display_buf[m]))m--;\
if (display_buf[m] == '-') {sign = '-'; m--;}\
while(m>=0){L_number = L_number*10 + display_buf[m] - '0'; m--;}}\
if (sign == '-')L_number = L_number * (-1);\
for(int m = 0; m <= 3; m++){result[3-m] = L_number; L_number = L_number >> 8;}\
long_to_slave_I2C;




/********************************************************************************************/
#define I2C_Tx_real_num \
L_number = 0;\
for (int m = 0; m < 4; m++){\
L_number += I2C_data[m];\
if(m<3) L_number = L_number << 8;}\
Display_real_num(L_number);



/********************************************************************************************/
#define I2C_Tx_float_num \
L_number = 0;\
for (int m = 0; m < 4; m++){\
L_number += I2C_data[m];\
if(m<3) L_number = L_number << 8;}\
expnt = I2C_data[4];\
float_to_askii(L_number, expnt,Sc_Num_string);\
TCCR2B = 2;\
TIMSK2 |= (1 << TOIE2);



/********************************************************************************************/
#define Multiplexer_demo \
\
MUX_cntl = I2C_data[0];	\
\
			eeprom_write_byte((uint8_t*)0x3FB, 0x03);{\
			switch (MUX_cntl){\
			case 0:	timer_T0_sub_with_interrupt(T0_delay_125us);break;\
			case 1: timer_T0_sub_with_interrupt(T0_delay_S_250us);break;\
			case 2:	timer_T0_sub_with_interrupt(T0_delay_375us);break;\
			case 3: timer_T0_sub_with_interrupt(T0_delay_500us);break;\
			case 4:	timer_T0_sub_with_interrupt(T0_delay_625us);break;\
			case 5: timer_T0_sub_with_interrupt(T0_delay_750us);break;\
			case 6: timer_T0_sub_with_interrupt(T0_delay_1250us);break;\
			case 7: timer_T0_sub_with_interrupt(T0_delay_2000us);break;\
			default: timer_T0_sub_with_interrupt(T0_delay_125us);break;}}\
\
			for(int p = 0; p <= 7; p++){display_buf[p] = (p + MUX_cntl)%8 + '0';}





/********************************************************************************************/
#define PCB_test \
TIMSK0 &= (~(1 << TOIE0));\
clear_digits; clear_display;\
Initialise_I2C_master_read;\
test_num = I2C_master_receive(1);\
switch(test_num){\
case '0': zero; break;\
case '1': one; break;\
case '2': two; break;\
case '3': three; break;\
case '4': four; break;\
case '5': five; break;\
case '6': six; break;\
case '7': seven; break;\
case '8': eight; break;\
case '9': nine; break;}\
test_digit = I2C_master_receive(0);\
switch(test_digit){\
case '0': digit_0; break;\
case '1': digit_1; break;\
case '2': digit_2; break;\
case '3': digit_3; break;\
case '4': digit_4; break;\
case '5': digit_5; break;\
case '6': digit_6; break;\
case '7': digit_7; break;}\
TWCR =  (1 << TWINT ) | (1 << TWEN ) | (1 << TWSTO );
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

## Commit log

2025-12-04 Create PCB-111000_V3_Fusion_parts_list
2025-12-07 Update PCB-111000_V3_Fusion_parts_list
2025-12-10 Create I2C_V27_0_CA_header file.h
2025-12-12 Create Fuse settings.odt
2025-12-13 Update Fuse settings.odt
2026-01-08 Create PCB111000_V3_track side.bmp
2026-01-08 Create PCB111000_V3_top side.bmp
